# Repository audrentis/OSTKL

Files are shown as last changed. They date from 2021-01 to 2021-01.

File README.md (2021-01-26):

# OSTKL
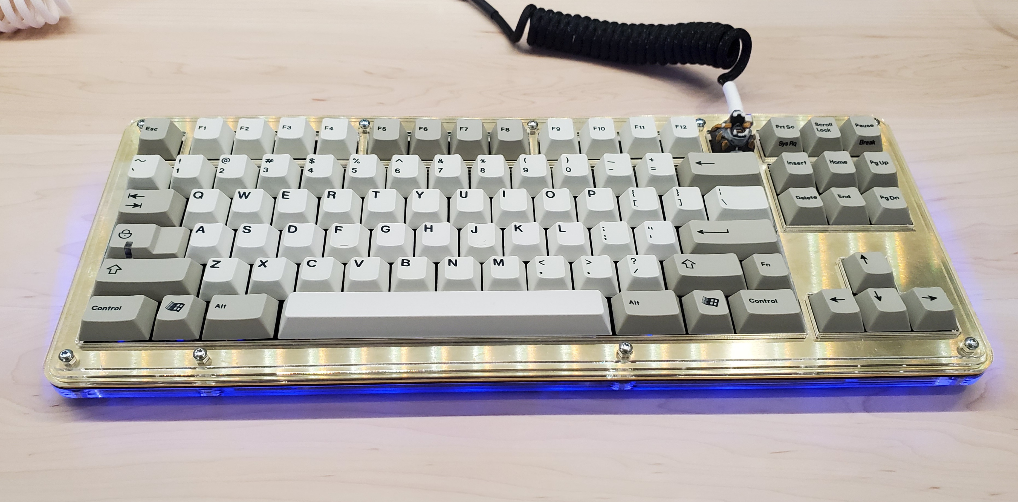
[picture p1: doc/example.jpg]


## About
A series of stacked acrylic cases designed around Hineybush's H87A and H88 PCBs.

* This case is designed to use 2mm acrylic and 1.5mm  switch plate 
* High profile height of approximately 8mm or 7.5mm based on layer thickness choice
* Independent case feet system allowing for the typing angles of approximately 7° or 0°
* 10mm case corners and offset case layers 
* Large USB cutout to accommodate various cables 
* Compatible with **NORTH FACING SPACEBAR** PCBs ONLY at this time 
* Case Versions for 
    * H88 Winkey
    * H88 Winkeyless
    * H87A Winkey
    * H87A Winkeyless 
* South-facing spacebar versions are a work-in-progress

## Assembly Guide can be found [here](https://github.com/audrentis/OSTKL/blob/main/doc/guide.pdf)

## Parts List
* A Hineybush PCB 
    * check for availability [here](https://hineybush.com/)
* 11 M3 x 14mm 4.5mm Hex Standoffs
* 22 M3 x 6mm Screws
* 4 rubber bump-ons 

#### Example Parts: 
Name | McMaster-Carr Part No. | Quantity
-|-|-
Standoff 4.5mm Hex, 14mm Long, M3 x 0.5mm Thread | 92080A010 | 11 pc 
Torx Screw M3 x 0.50mm Thread, 6mm Long | 92832A215 | 22 pc (1 100 pack)
Adhesive Back Polyurethane Bumpers | 95495K39 | 4 pc (1 72 pack)

## Plate Compatibility  
#### H87A
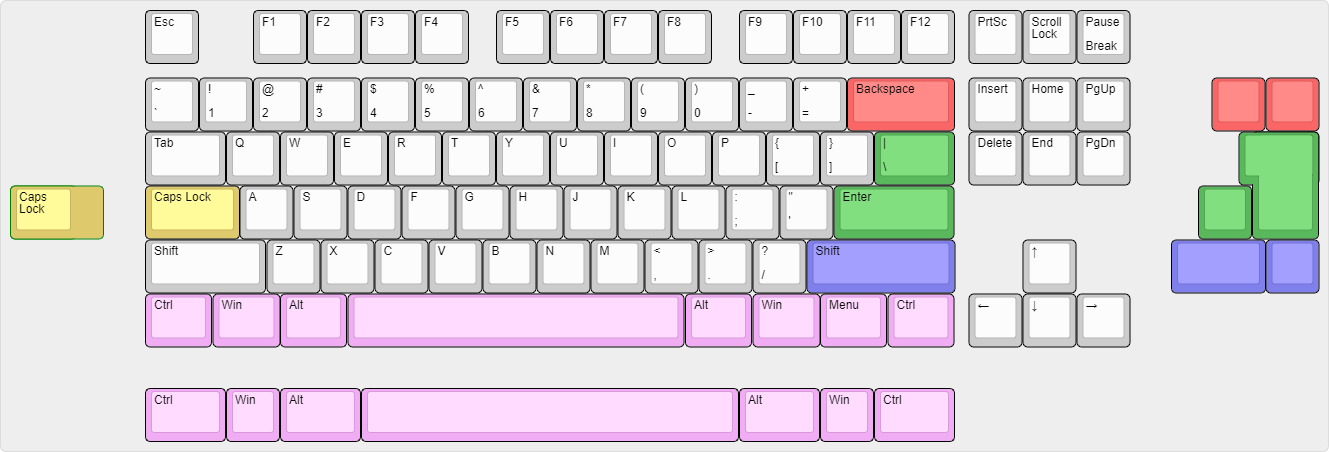
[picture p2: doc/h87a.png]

#### H88
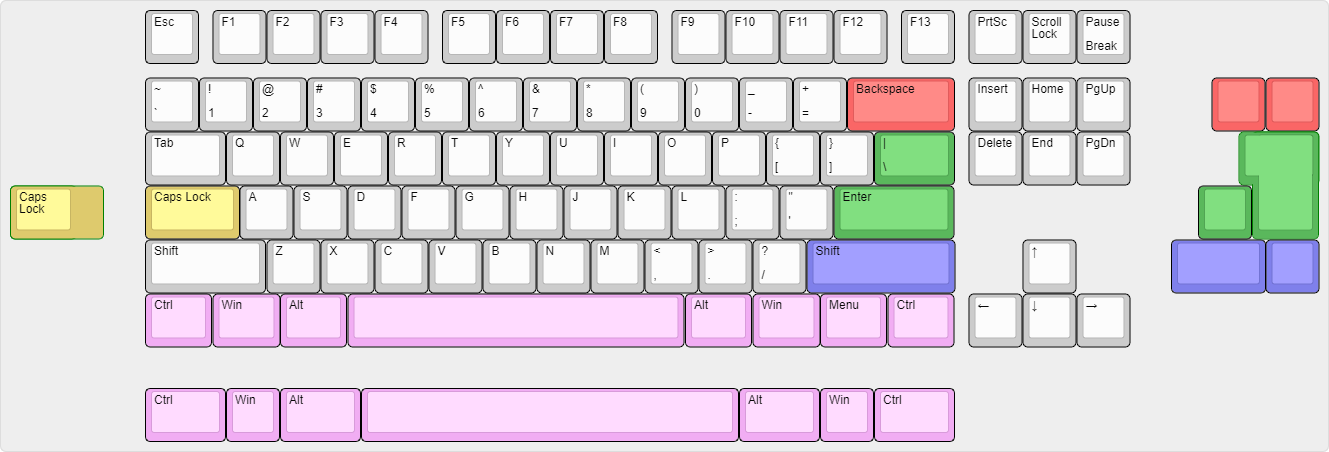
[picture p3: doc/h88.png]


*ISO and ANSI enter and left shift are in seperate plate files, however both share support for Tsangan layout* 

## Layer Guide
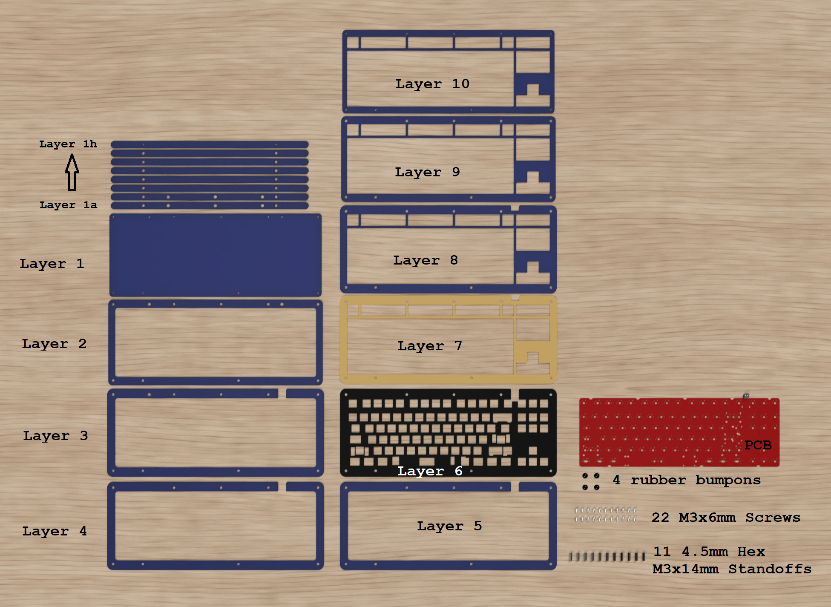
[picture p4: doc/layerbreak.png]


## Producing this case 
* Ensure scaling is set to millimeters 
    * widest case layers are approximately 150.98 mm x 372.37 mm
* Seperate .DXF files for each case and all plate types 
    * Case layers should be 2mm thick 
    * Switch Plates should be ~1.5mm thick 
* Layer 7 can be 2 or ~1.5mm based on desired high profile height ~7.5mm or ~8 mm or to provide an accent piece. 
* Laser cutting services I have used for prototypes are [Ponoko](https://www.ponoko.com/) and [SendCutSend](https://sendcutsend.com/) 
    * Make sure to follow design instructions when placing an order, including available stock sizes and kerf values. 
        * learn more about kerf [here](http://www.cutlasercut.com/resources/tips-and-advice/what-is-laser-kerf#:~:text=in%20a%20drawing-,What%20does%20kerf%20mean%3F,type%20and%20other%20conditional%20factors.)

# Disclaimer 
This repository is under the [GNU General Public License v3.0](https://github.com/audrentis/OSTKL/blob/main/LICENSE).  
If you wish to sell these, you should read it.

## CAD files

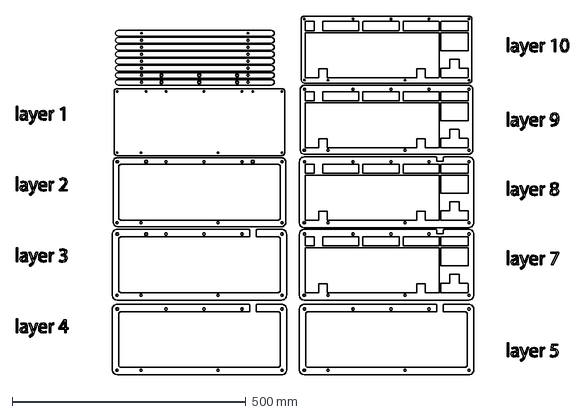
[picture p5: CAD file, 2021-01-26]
H87A North/WKL Master.dxf
1182.4 x 767.0 mm

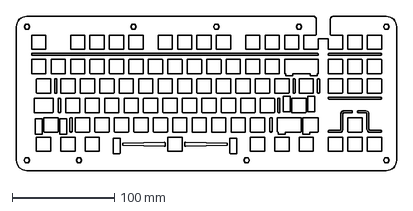
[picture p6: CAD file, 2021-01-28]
H87A South/7U ANSI Plate.dxf
372.4 x 151.0 mm

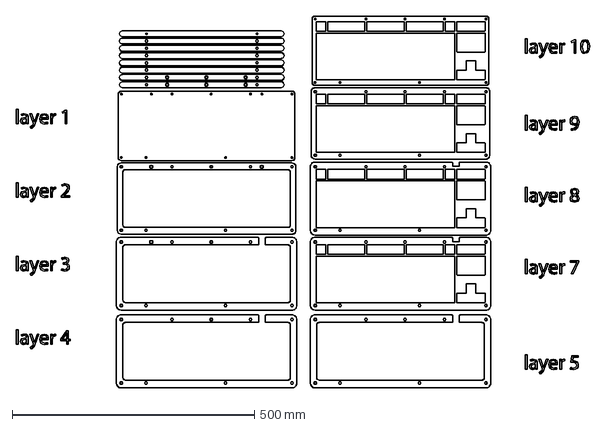
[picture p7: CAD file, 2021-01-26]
H88/WK Master.dxf
1182.4 x 767.0 mm

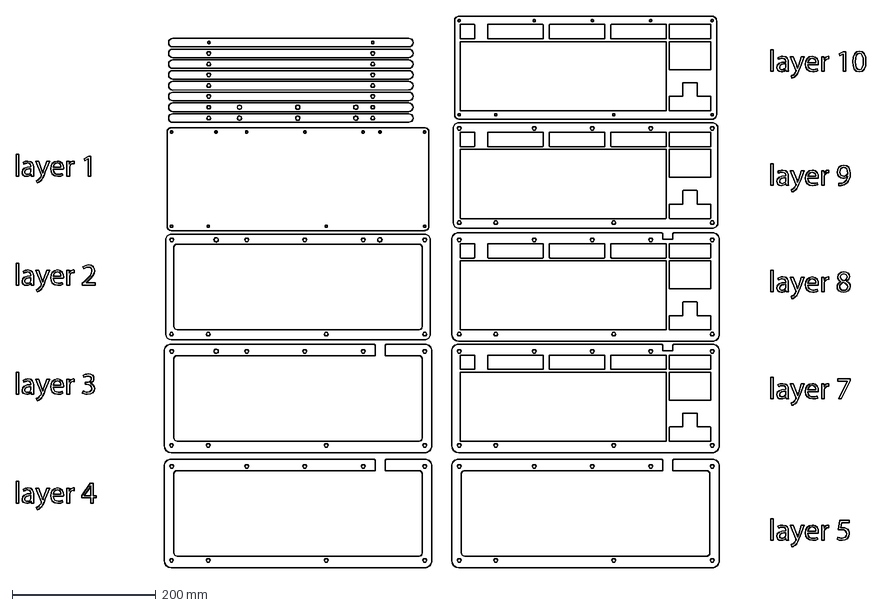
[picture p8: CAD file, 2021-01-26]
H87A North/WK Master.dxf
1182.4 x 767.0 mm

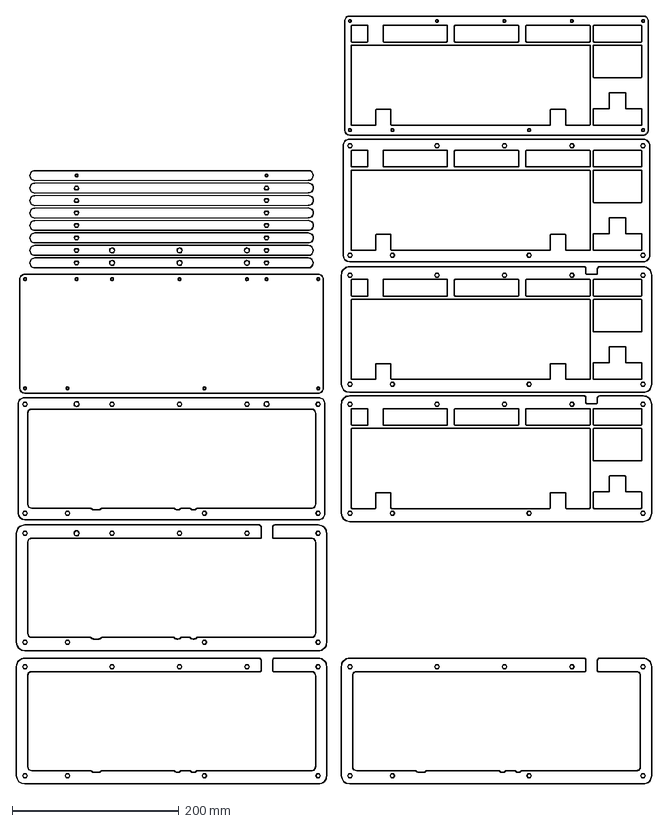
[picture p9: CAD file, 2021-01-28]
H87A South/WKL Master.dxf
762.4 x 922.0 mm

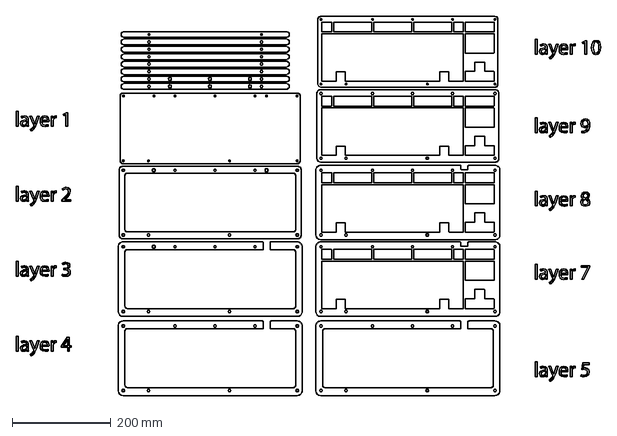
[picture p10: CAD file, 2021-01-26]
H88/WKL Master.dxf
1182.4 x 767.0 mm

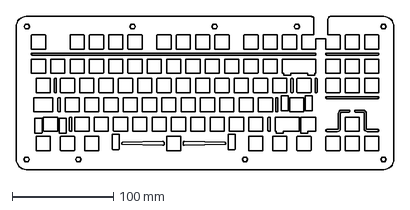
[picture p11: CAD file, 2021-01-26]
H87A North/7U ANSI Plate.dxf
372.4 x 151.0 mm

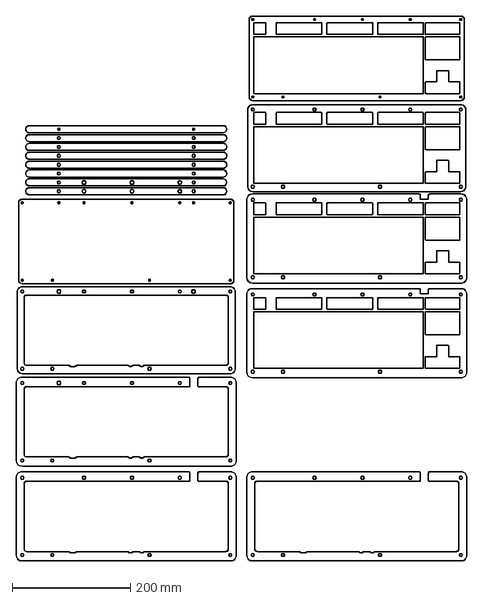
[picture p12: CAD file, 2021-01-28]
H87A South/WK Master.dxf
762.4 x 922.0 mm

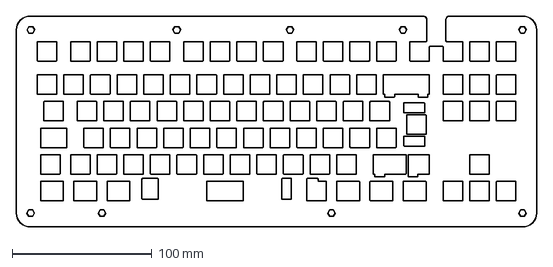
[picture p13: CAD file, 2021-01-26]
H88/ISO Plate.dxf
372.4 x 151.0 mm

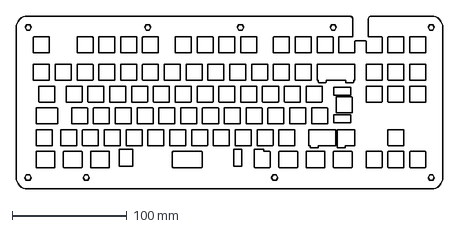
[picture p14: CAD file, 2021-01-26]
H87A North/ISO Plate.dxf
372.4 x 151.0 mm

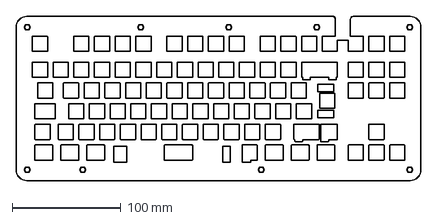
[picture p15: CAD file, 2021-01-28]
H87A South/ISO Plate.dxf
372.4 x 151.0 mm

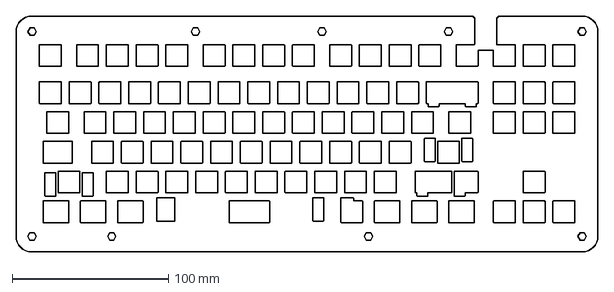
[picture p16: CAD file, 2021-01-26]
H88/ANSI Plate.dxf
372.4 x 151.0 mm

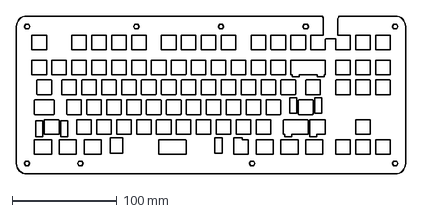
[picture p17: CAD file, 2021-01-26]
H87A North/ANSI Plate.dxf
372.4 x 151.0 mm

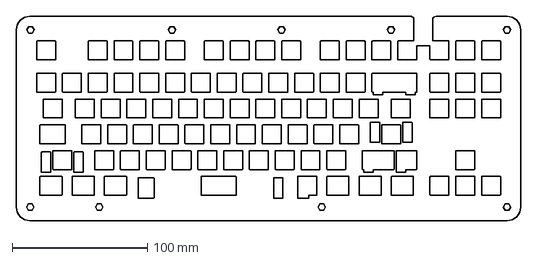
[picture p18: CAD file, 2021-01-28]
H87A South/ANSI Plate.dxf
372.4 x 151.0 mm

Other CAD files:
H88/7U ANSI Plate.dxf

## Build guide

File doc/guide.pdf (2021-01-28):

# OSTKL Assembly Guide

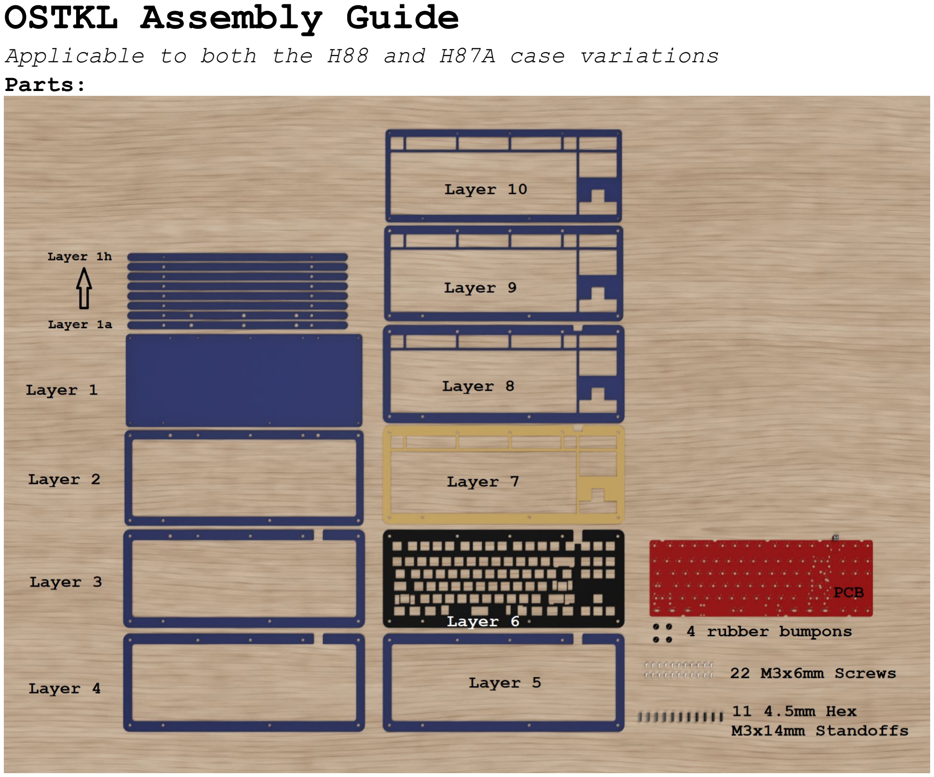
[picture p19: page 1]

Applicable to both the H88 and H87A case variations
Parts:

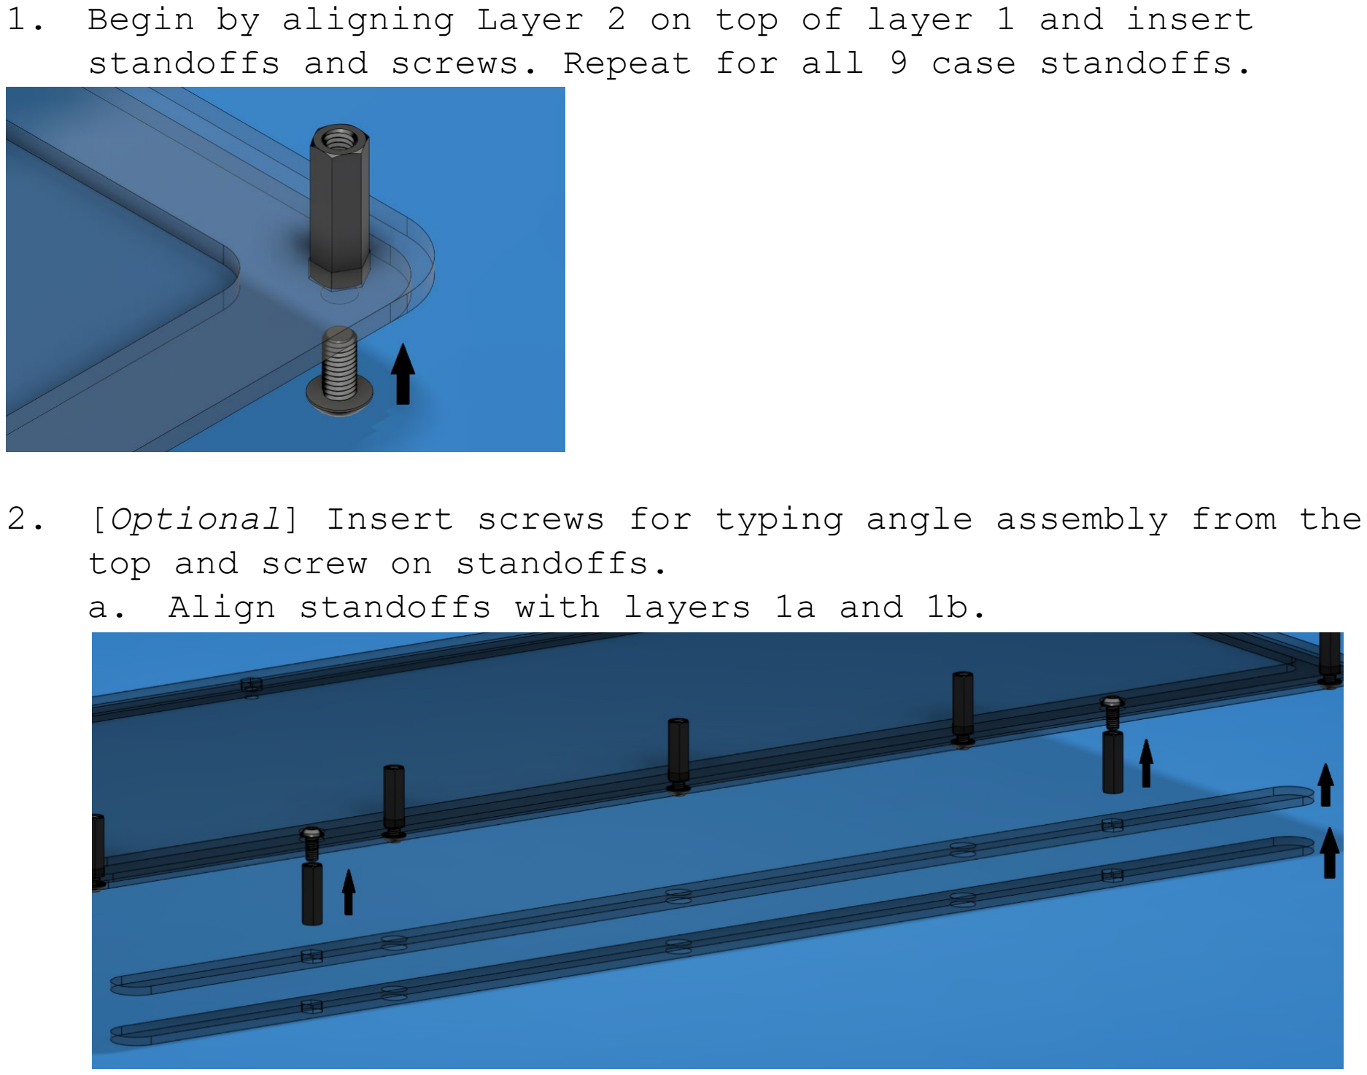
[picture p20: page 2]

1. Begin by aligning Layer 2 on top of layer 1 and insert standoffs and screws. Repeat for all 9 case standoffs.
2. [Optional] Insert screws for typing angle assembly from the top and screw on standoffs.
a. Align standoffs with layers 1a and 1b.

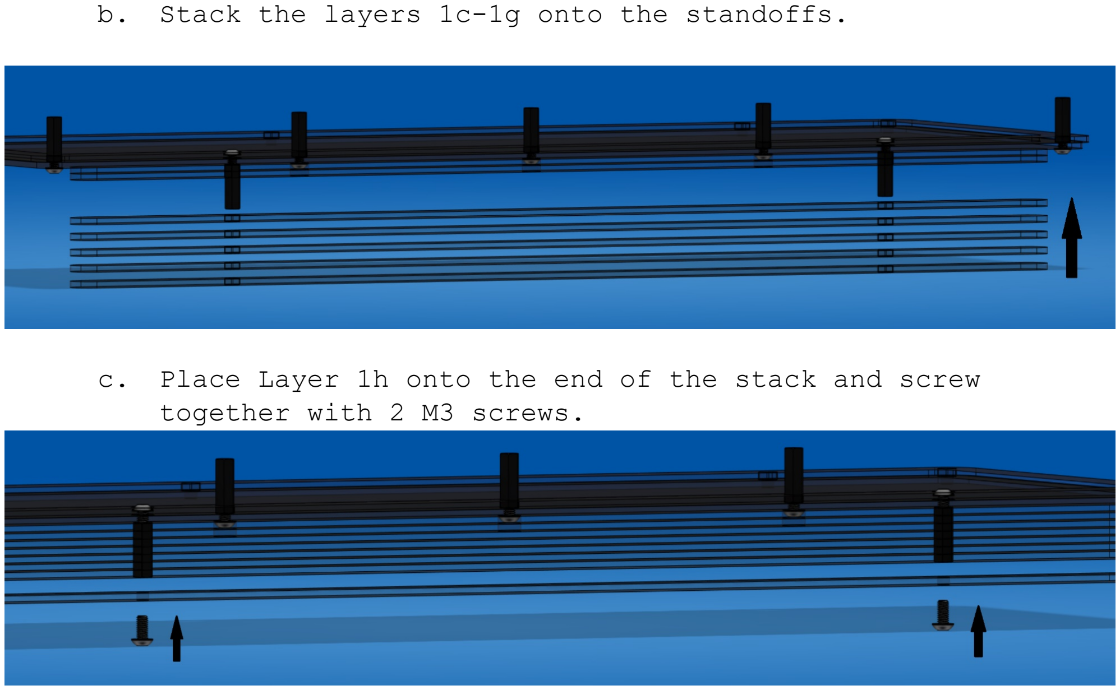
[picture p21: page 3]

b. Stack the layers 1c-1g onto the standoffs.
c. Place Layer 1h onto the end of the stack and screw together with 2 M3 screws.

3. Press layers 3 through 5 onto the case standoffs.

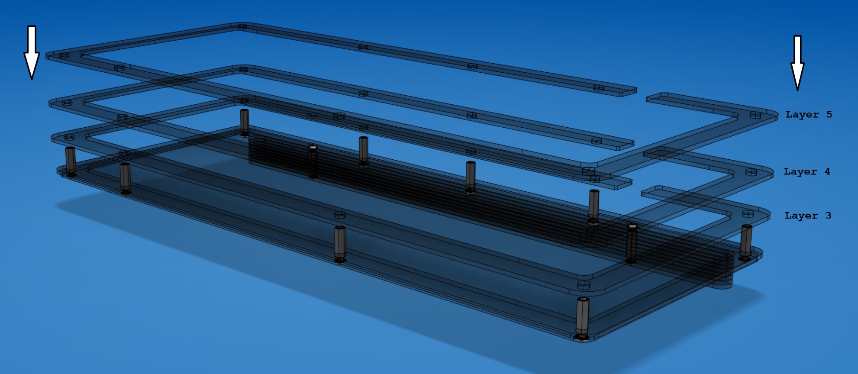
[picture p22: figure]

4. Solder together your PCB and plate assembly

5. Align the plate assembly to the standoffs and slowly press down.

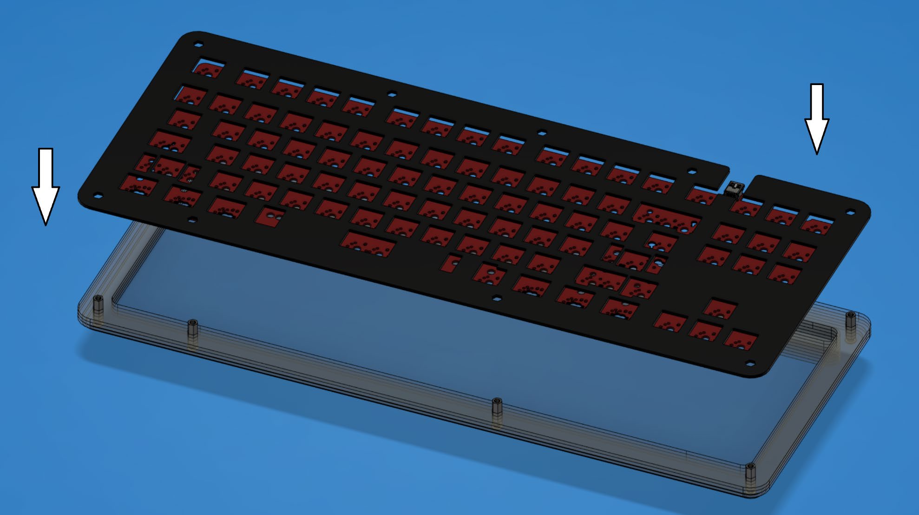
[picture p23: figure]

6. Begin placing layers 7, 8, and 9 onto the standoffs.

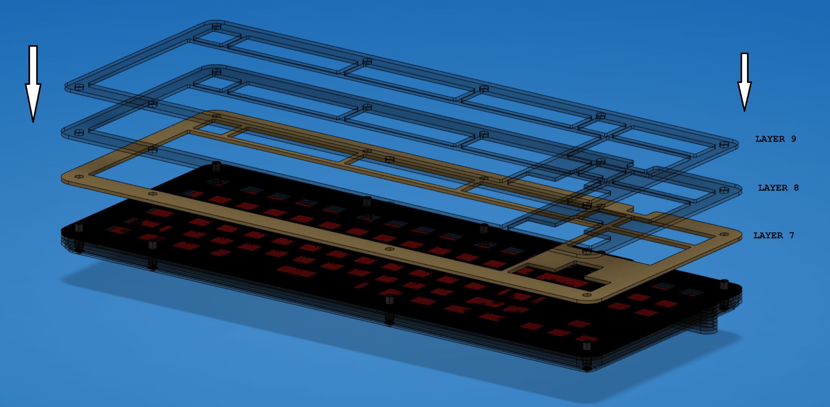
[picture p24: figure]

7. Align Layer 10 to Layer 9 and screw together with 9 M3 screws.

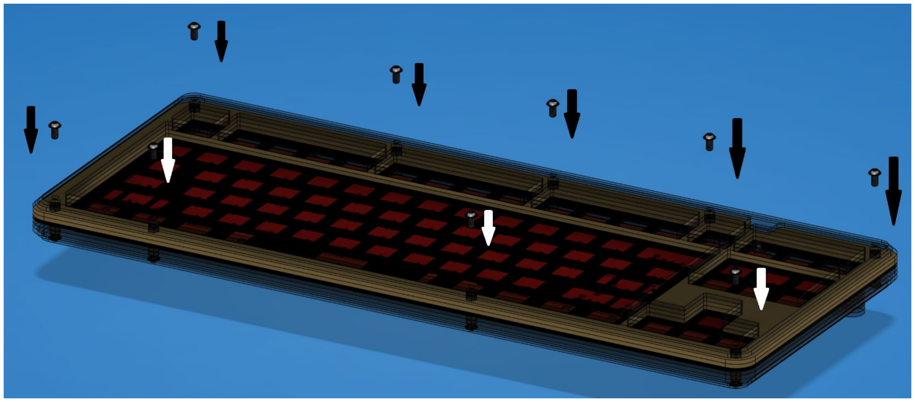
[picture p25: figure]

8. Put rubber bump-ons on corners of the case and optionally the typing angle assembly.

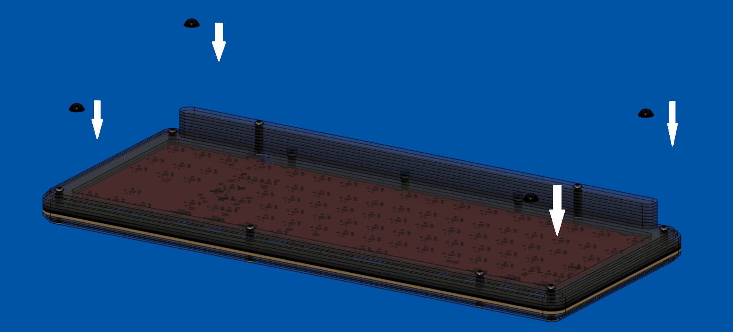
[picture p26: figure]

9. Put on keycaps and enjoy!

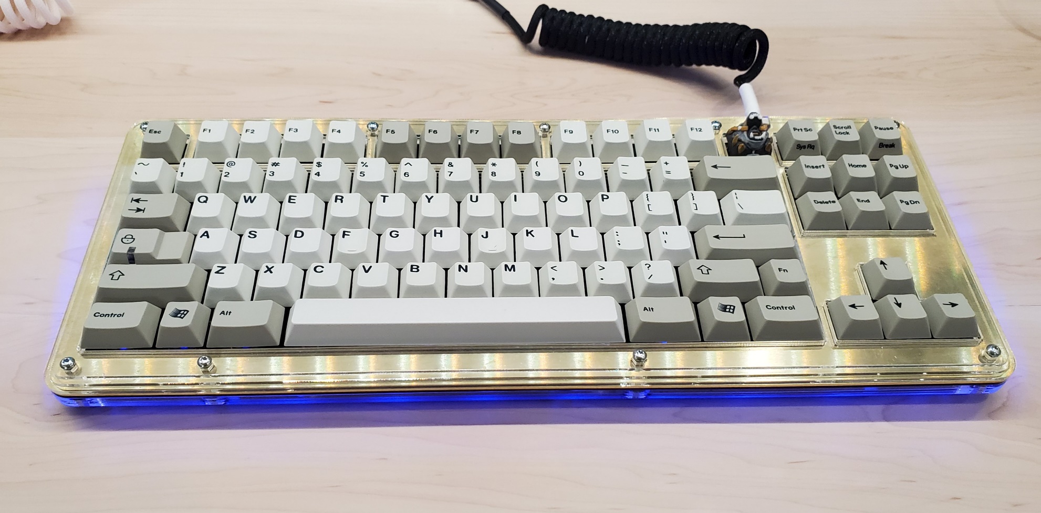
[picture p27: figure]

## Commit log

2021-01-23 upd readme.md and add individual files
    [Base.dxf, Closed1.dxf, Closed2.dxf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]
2021-01-23 update plate compatability
2021-01-24 add plates
    [Plate - ANSI Acoustic Plate.dxf, Plate - ANSI Plate.dxf, Plate - ISO Acoustic Plate.dxf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]
2021-01-26 Added H88 Case Masters and H87A plates
    double checking H87A case masters
    [7U ANSI Plate.dxf, ANSI Plate.dxf, ISO Plate.dxf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]
2021-01-26 Add H87A North Case Masters
    [7U ANSI Plate.dxf, ANSI Plate.dxf, ISO Plate.dxf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]
2021-01-26 Update README.md and release assembly guide
    [7U ANSI Plate.dxf, ANSI Plate.dxf, ISO Plate.dxf]
2021-01-26 update master sketches
    [WK Master.dxf, WKL Master.dxf]
2021-01-28 Update Documentation
    [7U ANSI Plate.dxf, ANSI Plate.dxf, ISO Plate.dxf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]
